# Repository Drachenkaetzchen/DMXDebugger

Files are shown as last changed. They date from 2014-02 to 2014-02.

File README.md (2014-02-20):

# DMX/RDM Adapter / RS485 Hub

This is a board which allows you to:
- Interconnect any standard DMX plugs, which includes XLR 3 pin male+female, XLR 5 pin male+female and RJ45
- Flip the data lines for each port in case of wiring error
- Connect each plug to an internal RS485 hub (in "direct" mode, each Data+/Data- lines are connected to each other)
- Terminate each port and enable/disable RX (only if port is connected to the RS485 hub)
- Connect a logic probe to the RS485 hub or to the secondary data ports (useful for the OLA logic sniffer)
- Display RX/TX status (RS485 hub mode only)
- Powered via battery (9V) or USB

# Applications

## Interconnect DMX plug formats directly

1. This mode works unpowered. You don't need to connect a battery or USB
2. Flip all switches from "TO HUB" to "DIRECT"
3. Connect exactly 2 plugs you wish to connect. If you connect more, data collisions can occur on the bus

## Interconnect DMX plug formats via the RS485 hub

1. This mode requires power. Connect a 9V battery or USB and flip the power switch to the specific "ON" position (either USB or BATTERY)
2. Flip the switches for all used ports from "DIRECT" to "HUB"
3. Connect as many plugs as you like
4. The LEDs should indicate RX/TX status

## Retrieve the data on the DMX bus via a logic analyzer

1. Set up as described in "Interconnect DMX plug formats via the RS485 hub"
2. Connect your logic probe to the GND and DATA pins on the bottom right

## Retrieve the data of the DMX secondary data lines

1. This mode works unpowered. However, you need an RS485 driver (like the SN75176) to convert the differential signal into logic levels
2. Connect your probe to the secondary data port

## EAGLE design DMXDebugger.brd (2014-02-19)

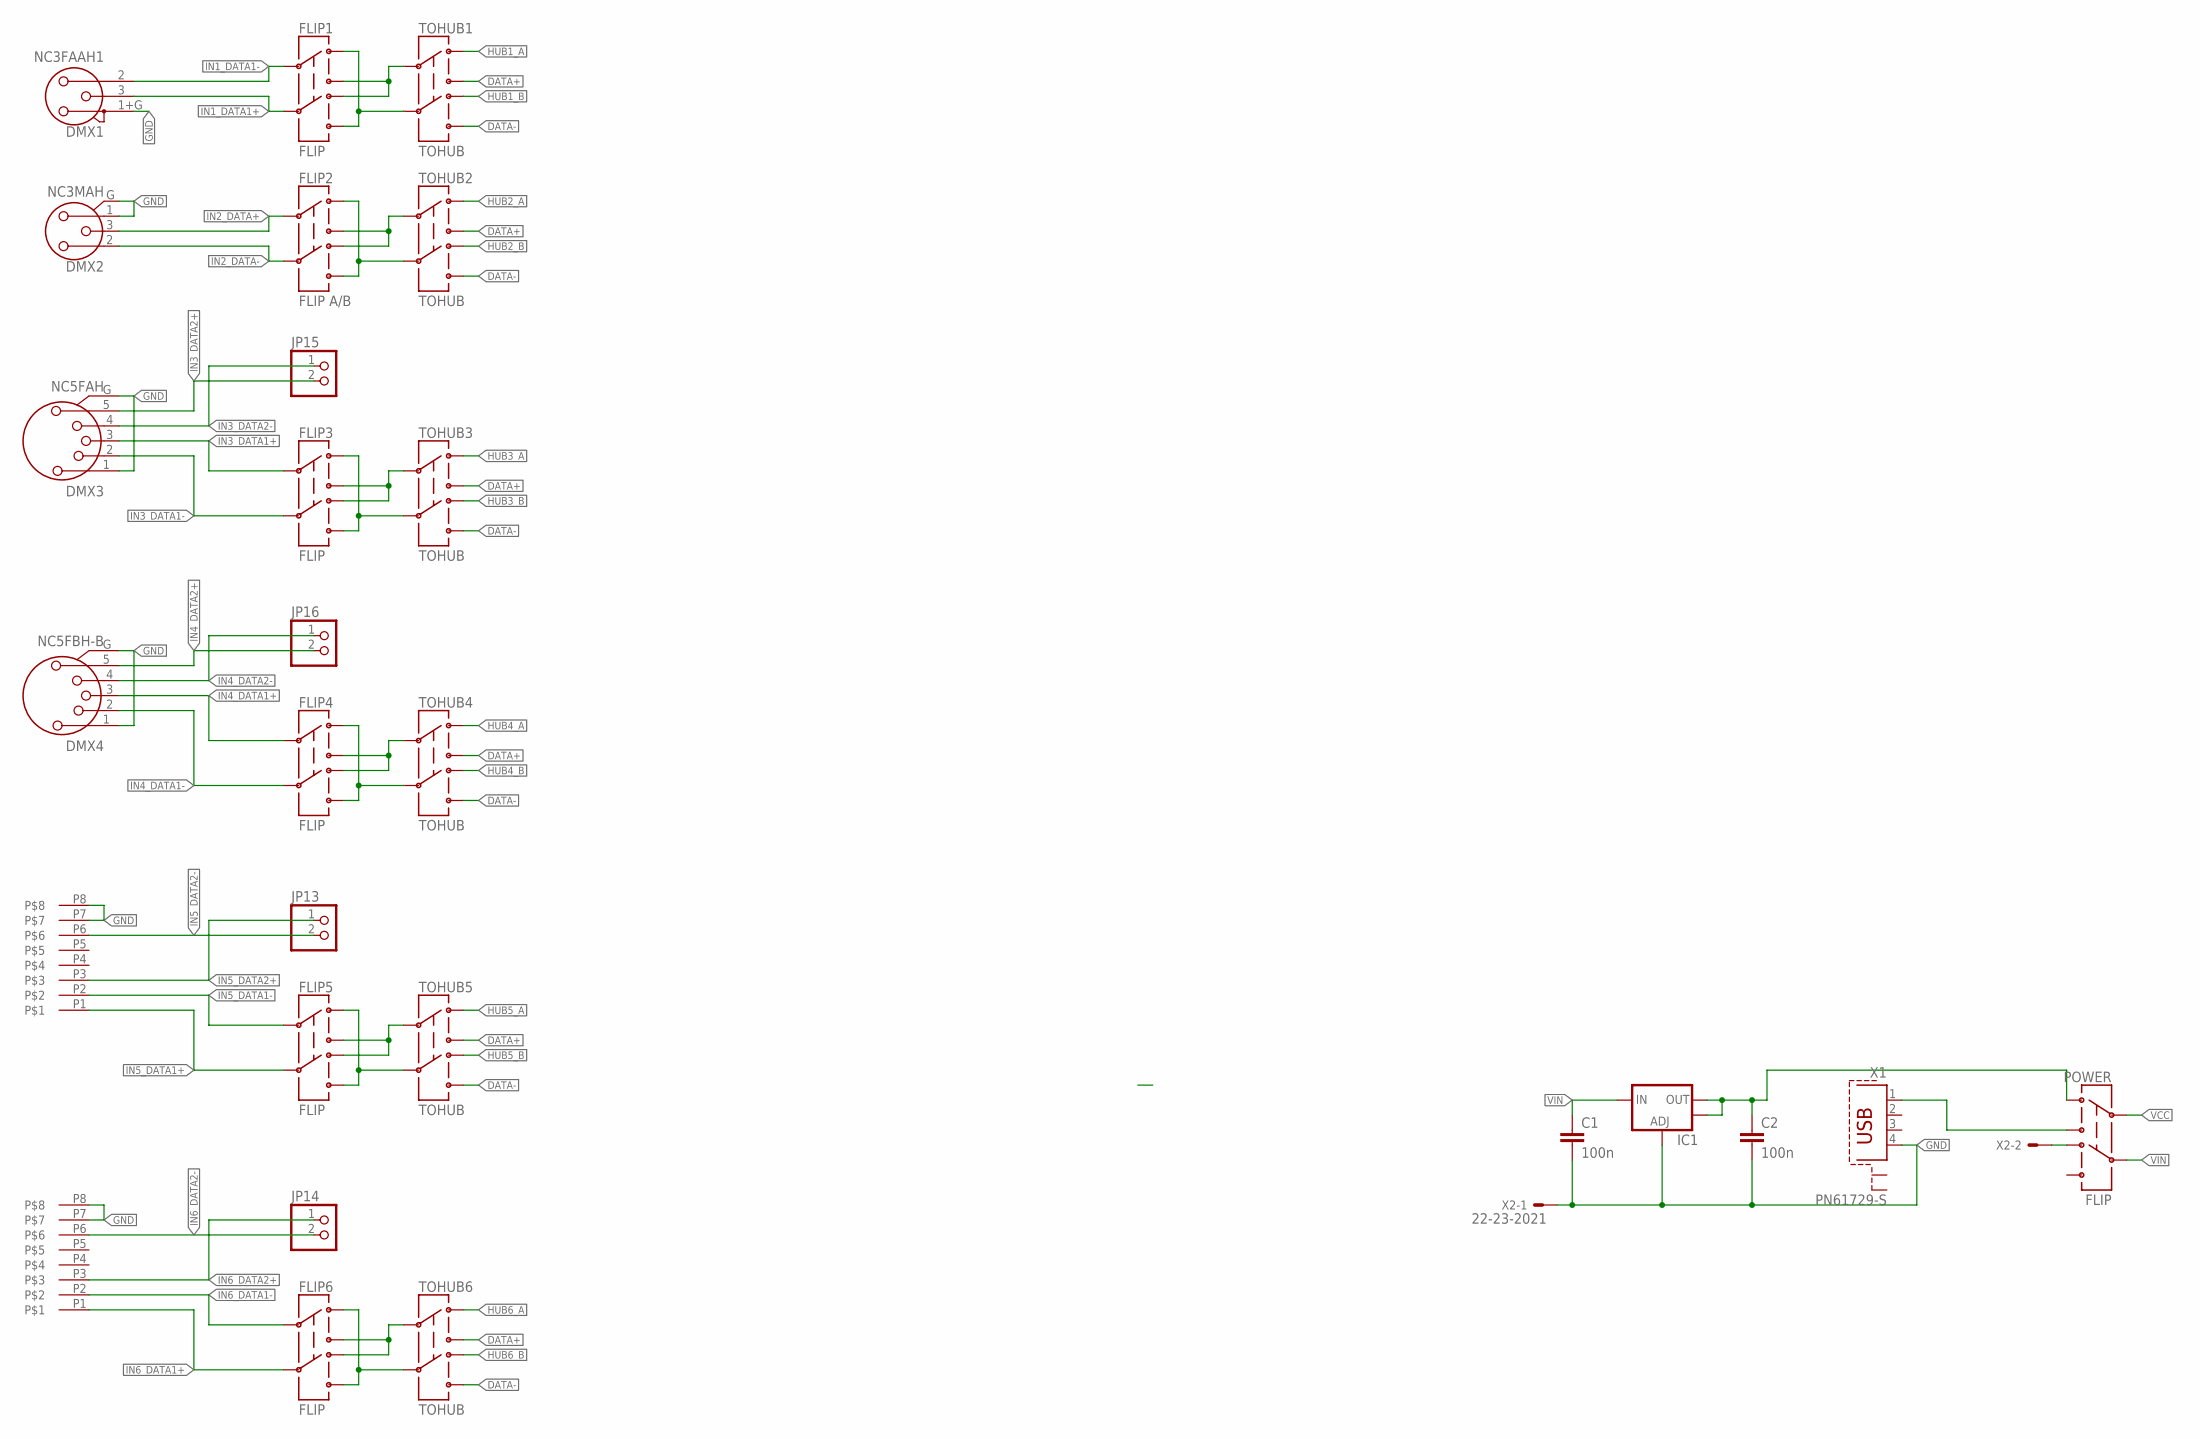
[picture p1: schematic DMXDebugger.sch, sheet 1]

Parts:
C1, C2: 100n; C1206
DMX1: NC3FAAH1; NC3FAH1
DMX2: NC3MAH; NC3FAH2
DMX3: NC5FAH
DMX4: NC5FBH-B
DMX5, DMX6: RJHS508; P-RJHS-538X
FLIP1, FLIP3, FLIP4, FLIP5, FLIP6: FLIP; MSS-2235
FLIP2: FLIP A/B; MSS-2235
IC1: V_REG_LM1117SOT223; SOT223
JP13, JP14, JP15, JP16: PINHD-1X2; 1X02
POWER: FLIP; MSS-2235
TOHUB1, TOHUB2, TOHUB3, TOHUB4, TOHUB5, TOHUB6: TOHUB; MSS-2235
X1: PN61729-S
X2: 22-23-2021

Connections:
DATA+: TOHUB1.3, TOHUB2.3, TOHUB3.3, TOHUB4.3, TOHUB5.3, TOHUB6.3
DATA-: TOHUB1.4 (6), TOHUB2.4 (6), TOHUB3.4 (6), TOHUB4.4 (6), TOHUB5.4 (6), TOHUB6.4 (6)
GND: C1.2, C2.2, DMX1.1+G (1), DMX2.1 (2), DMX2.G, DMX3.1, DMX3.G, DMX4.1, DMX4.G, DMX5.P7, DMX5.P8, DMX6.P7, DMX6.P8, IC1.1 (ADJ), X1.4, X2.1; also elsewhere on the board
HUB1_A: TOHUB1.1; also elsewhere on the board
HUB1_B: TOHUB1.6 (4); also elsewhere on the board
HUB2_A: TOHUB2.1; also elsewhere on the board
HUB2_B: TOHUB2.6 (4); also elsewhere on the board
HUB3_A: TOHUB3.1; also elsewhere on the board
HUB3_B: TOHUB3.6 (4); also elsewhere on the board
HUB4_A: TOHUB4.1; also elsewhere on the board
HUB4_B: TOHUB4.6 (4); also elsewhere on the board
HUB5_A: TOHUB5.1; also elsewhere on the board
HUB5_B: TOHUB5.6 (4); also elsewhere on the board
HUB6_A: TOHUB6.1; also elsewhere on the board
HUB6_B: TOHUB6.6 (4); also elsewhere on the board
IN1_DATA1+: DMX1.3, FLIP1.5
IN1_DATA1-: DMX1.2, FLIP1.2
IN2_DATA+: DMX2.3, FLIP2.2
IN2_DATA-: DMX2.2 (1), FLIP2.5
IN3_DATA1+: DMX3.3, FLIP3.2
IN3_DATA1-: DMX3.2, FLIP3.5
IN3_DATA2+: DMX3.5, JP15.2
IN3_DATA2-: DMX3.4, JP15.1
IN4_DATA1+: DMX4.3, FLIP4.2
IN4_DATA1-: DMX4.2, FLIP4.5
IN4_DATA2+: DMX4.5, JP16.2
IN4_DATA2-: DMX4.4, JP16.1
IN5_DATA1+: DMX5.P1, FLIP5.5
IN5_DATA1-: DMX5.P2, FLIP5.2
IN5_DATA2+: DMX5.P3, JP13.1
IN5_DATA2-: DMX5.P6, JP13.2
IN6_DATA1+: DMX6.P1, FLIP6.5
IN6_DATA1-: DMX6.P2, FLIP6.2
IN6_DATA2+: DMX6.P3, JP14.1
IN6_DATA2-: DMX6.P6, JP14.2
unnamed: POWER.6 (4), X2.2
unnamed: POWER.3, X1.1
unnamed: FLIP1.3, FLIP1.6 (4), TOHUB1.2
unnamed: FLIP1.1, FLIP1.4 (6), TOHUB1.5
unnamed: FLIP2.1, FLIP2.4 (6), TOHUB2.5
unnamed: FLIP2.3, FLIP2.6 (4), TOHUB2.2
unnamed: FLIP3.1, FLIP3.4 (6), TOHUB3.5
unnamed: FLIP4.1, FLIP4.4 (6), TOHUB4.5
unnamed: FLIP5.1, FLIP5.4 (6), TOHUB5.5
unnamed: FLIP3.3, FLIP3.6 (4), TOHUB3.2
unnamed: FLIP4.3, FLIP4.6 (4), TOHUB4.2
unnamed: FLIP5.3, FLIP5.6 (4), TOHUB5.2
unnamed: FLIP6.1, FLIP6.4 (6), TOHUB6.5
unnamed: FLIP6.3, FLIP6.6 (4), TOHUB6.2
VCC: POWER.2; also elsewhere on the board
VIN: C1.1, IC1.3 (IN), POWER.5
VOUT: C2.1, IC1.2 (OUT), IC1.4 (OUT), POWER.1

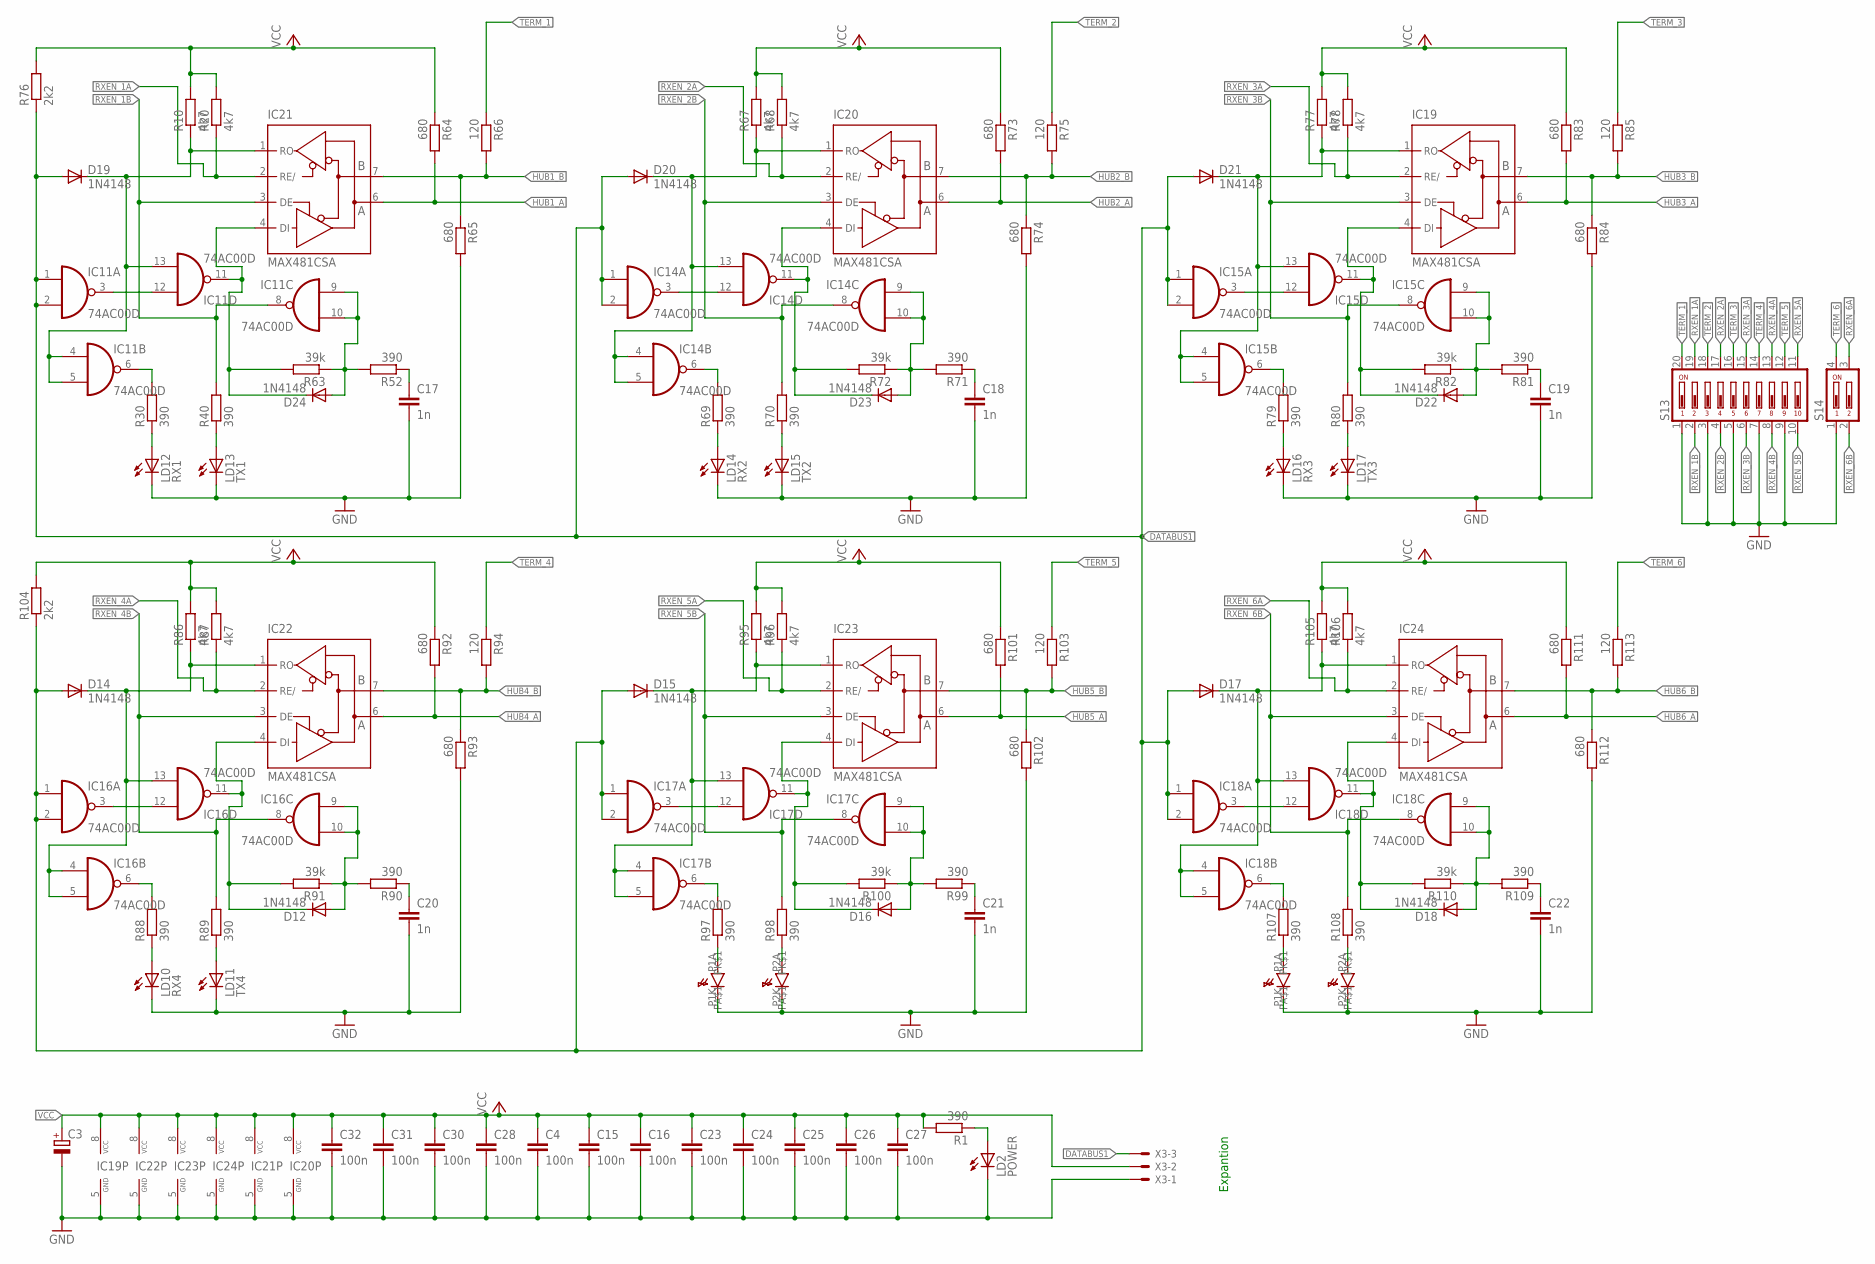
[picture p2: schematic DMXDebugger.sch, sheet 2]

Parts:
C3: CPOL-EUD; PANASONIC_D
C4, C15, C16, C23, C24, C25, C26, C27, C28, C30, C31, C32: 100n; C1206
C17, C18, C19, C20, C21, C22: 1n; C1206
D12, D14, D15, D16, D17, D18, D19, D20, D21, D22, D23, D24: 1N4148; MINIMELF
DMX5, DMX6: RJHS508; P-RJHS-538X
IC11, IC14, IC15, IC16, IC17, IC18: 74AC00D; SO14
IC19, IC20, IC21, IC22, IC23, IC24: MAX481CSA; SO08
LD2: POWER; CHIP-LED0603
LD10: RX4; CHIP-LED0603
LD11: TX4; CHIP-LED0603
LD12: RX1; CHIP-LED0603
LD13: TX1; CHIP-LED0603
LD14: RX2; CHIP-LED0603
LD15: TX2; CHIP-LED0603
LD16: RX3; CHIP-LED0603
LD17: TX3; CHIP-LED0603
R1, R30, R40, R52, R69, R70, R71, R79, R80, R81, R88, R89, R90, R97, R98, R99, R107, R108, R109: 390; R1206
R10, R20, R67, R68, R77, R78, R86, R87, R95, R96, R105, R106: 4k7; R1206
R63, R72, R82, R91, R100, R110: 39k; R1206
R64, R65, R73, R74, R83, R84, R92, R93, R101, R102, R111, R112: 680; R1206
R66, R75, R85, R94, R103, R113: 120; R1206
R76, R104: 2k2; R1206
S13: DIP10YL
S14: DIP02YL
X3: 22-23-2031

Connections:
DATABUS1: D14.A, D15.A, D17.A, D19.A, D20.A, D21.A, IC11.1 (I0), IC11.2 (I1), IC14.1 (I0), IC14.2 (I1), IC15.1 (I0), IC15.2 (I1), IC16.1 (I0), IC16.2 (I1), IC17.1 (I0), IC17.2 (I1), IC18.1 (I0), IC18.2 (I1), R76.1, R104.1, X3.3
GND: C3.-, C4.2, C15.2, C16.2, C17.2, C18.2, C19.2, C20.2, C21.2, C22.2, C23.2, C24.2, C25.2, C26.2, C27.2, C28.2, C30.2, C31.2, C32.2, DMX5.P1K (PK$1), DMX5.P2K (PK$1), DMX6.P1K (PK$1), DMX6.P2K (PK$1), IC11.7 (GND), IC14.7 (GND), IC15.7 (GND), IC16.7 (GND), IC17.7 (GND), IC18.7 (GND), IC19.5 (GND), IC20.5 (GND), IC21.5 (GND), IC22.5 (GND), IC23.5 (GND), IC24.5 (GND), LD2.C, LD10.C, LD11.C, LD12.C, LD13.C, LD14.C, LD15.C, LD16.C, LD17.C, R65.2, R74.2, R84.2, R93.2, R102.2, R112.2, S13.1, S13.3, S13.5, S13.7, S13.9, S14.1, X3.1; also elsewhere on the board
HUB1_A: IC21.6 (A), R64.2; also elsewhere on the board
HUB1_B: IC21.7 (B), R65.1, R66.2; also elsewhere on the board
HUB2_A: IC20.6 (A), R73.2; also elsewhere on the board
HUB2_B: IC20.7 (B), R74.1, R75.2; also elsewhere on the board
HUB3_A: IC19.6 (A), R83.2; also elsewhere on the board
HUB3_B: IC19.7 (B), R84.1, R85.2; also elsewhere on the board
HUB4_A: IC22.6 (A), R92.2; also elsewhere on the board
HUB4_B: IC22.7 (B), R93.1, R94.2; also elsewhere on the board
HUB5_A: IC23.6 (A), R101.2; also elsewhere on the board
HUB5_B: IC23.7 (B), R102.1, R103.2; also elsewhere on the board
HUB6_A: IC24.6 (A), R111.2; also elsewhere on the board
HUB6_B: IC24.7 (B), R112.1, R113.2; also elsewhere on the board
unnamed: LD2.A, R1.1
unnamed: LD13.A, R40.1
unnamed: LD12.A, R30.1
unnamed: D19.C, IC11.4 (I0), IC11.5 (I1), IC11.13 (I1), IC21.1 (RO), R10.1
unnamed: IC11.3 (O), IC11.12 (I0)
unnamed: IC11.6 (O), R30.2
unnamed: D24.A, IC11.9 (I0), IC11.10 (I1), R52.2, R63.1
unnamed: D24.C, IC11.11 (O), IC21.4 (DI), R63.2
unnamed: C17.1, R52.1
unnamed: LD15.A, R70.1
unnamed: LD14.A, R69.1
unnamed: D20.C, IC14.4 (I0), IC14.5 (I1), IC14.13 (I1), IC20.1 (RO), R67.1
unnamed: IC14.3 (O), IC14.12 (I0)
unnamed: IC14.6 (O), R69.2
unnamed: D23.A, IC14.9 (I0), IC14.10 (I1), R71.2, R72.1
unnamed: D23.C, IC14.11 (O), IC20.4 (DI), R72.2
unnamed: C18.1, R71.1
unnamed: LD17.A, R80.1
unnamed: LD16.A, R79.1
unnamed: D21.C, IC15.4 (I0), IC15.5 (I1), IC15.13 (I1), IC19.1 (RO), R77.1
unnamed: IC15.3 (O), IC15.12 (I0)
unnamed: IC15.6 (O), R79.2
unnamed: D22.A, IC15.9 (I0), IC15.10 (I1), R81.2, R82.1
unnamed: D22.C, IC15.11 (O), IC19.4 (DI), R82.2
unnamed: C19.1, R81.1
unnamed: LD11.A, R89.1
unnamed: LD10.A, R88.1
unnamed: D14.C, IC16.4 (I0), IC16.5 (I1), IC16.13 (I1), IC22.1 (RO), R86.1
unnamed: IC16.3 (O), IC16.12 (I0)
unnamed: IC16.6 (O), R88.2
unnamed: D12.A, IC16.9 (I0), IC16.10 (I1), R90.2, R91.1
unnamed: D12.C, IC16.11 (O), IC22.4 (DI), R91.2
unnamed: C20.1, R90.1
unnamed: DMX5.P2A (PA$1), R98.1
unnamed: DMX5.P1A (PA$1), R97.1
unnamed: D15.C, IC17.4 (I0), IC17.5 (I1), IC17.13 (I1), IC23.1 (RO), R95.1
unnamed: IC17.3 (O), IC17.12 (I0)
unnamed: IC17.6 (O), R97.2
unnamed: D16.A, IC17.9 (I0), IC17.10 (I1), R99.2, R100.1
unnamed: D16.C, IC17.11 (O), IC23.4 (DI), R100.2
unnamed: C21.1, R99.1
unnamed: DMX6.P2A (PA$1), R108.1
unnamed: DMX6.P1A (PA$1), R107.1
unnamed: D17.C, IC18.4 (I0), IC18.5 (I1), IC18.13 (I1), IC24.1 (RO), R105.1
unnamed: IC18.3 (O), IC18.12 (I0)
unnamed: IC18.6 (O), R107.2
unnamed: D18.A, IC18.9 (I0), IC18.10 (I1), R109.2, R110.1
unnamed: D18.C, IC18.11 (O), IC24.4 (DI), R110.2
unnamed: C22.1, R109.1
RXEN_1A: IC21.2 (RE/), R20.1, S13.19
RXEN_1B: IC11.8 (O), IC21.3 (DE), R40.2, S13.2
RXEN_2A: IC20.2 (RE/), R68.1, S13.17
RXEN_2B: IC14.8 (O), IC20.3 (DE), R70.2, S13.4
RXEN_3A: IC19.2 (RE/), R78.1, S13.15
RXEN_3B: IC15.8 (O), IC19.3 (DE), R80.2, S13.6
RXEN_4A: IC22.2 (RE/), R87.1, S13.13
RXEN_4B: IC16.8 (O), IC22.3 (DE), R89.2, S13.8
RXEN_5A: IC23.2 (RE/), R96.1, S13.11
RXEN_5B: IC17.8 (O), IC23.3 (DE), R98.2, S13.10
RXEN_6A: IC24.2 (RE/), R106.1, S14.3
RXEN_6B: IC18.8 (O), IC24.3 (DE), R108.2, S14.2
TERM_1: R66.1, S13.20
TERM_2: R75.1, S13.18
TERM_3: R85.1, S13.16
TERM_4: R94.1, S13.14
TERM_5: R103.1, S13.12
TERM_6: R113.1, S14.4
VCC: C3.+, C4.1, C15.1, C16.1, C23.1, C24.1, C25.1, C26.1, C27.1, C28.1, C30.1, C31.1, C32.1, IC11.14 (VCC), IC14.14 (VCC), IC15.14 (VCC), IC16.14 (VCC), IC17.14 (VCC), IC18.14 (VCC), IC19.8 (VCC), IC20.8 (VCC), IC21.8 (VCC), IC22.8 (VCC), IC23.8 (VCC), IC24.8 (VCC), R1.2, R10.2, R20.2, R64.1, R67.2, R68.2, R73.1, R76.2, R77.2, R78.2, R83.1, R86.2, R87.2, R92.1, R95.2, R96.2, R101.1, R104.2, R105.2, R106.2, R111.1, X3.2; also elsewhere on the board

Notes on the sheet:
Expantion

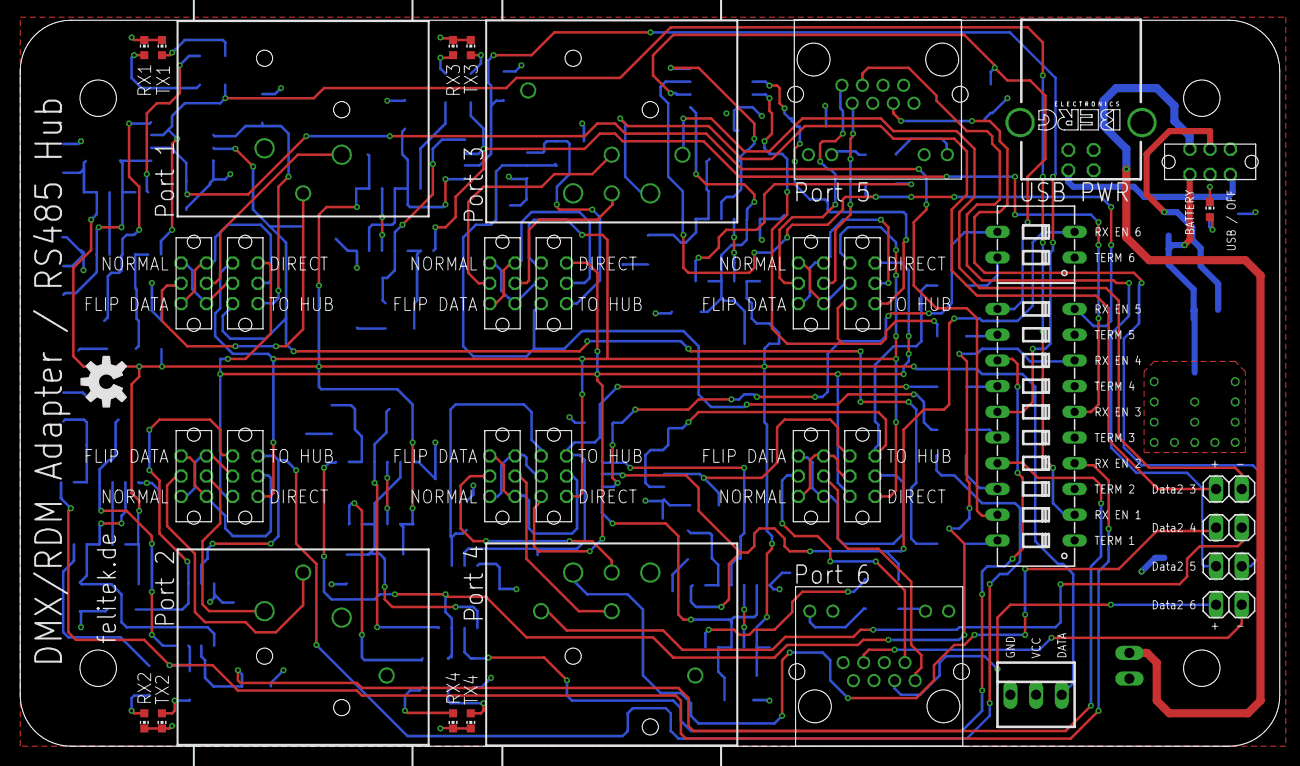
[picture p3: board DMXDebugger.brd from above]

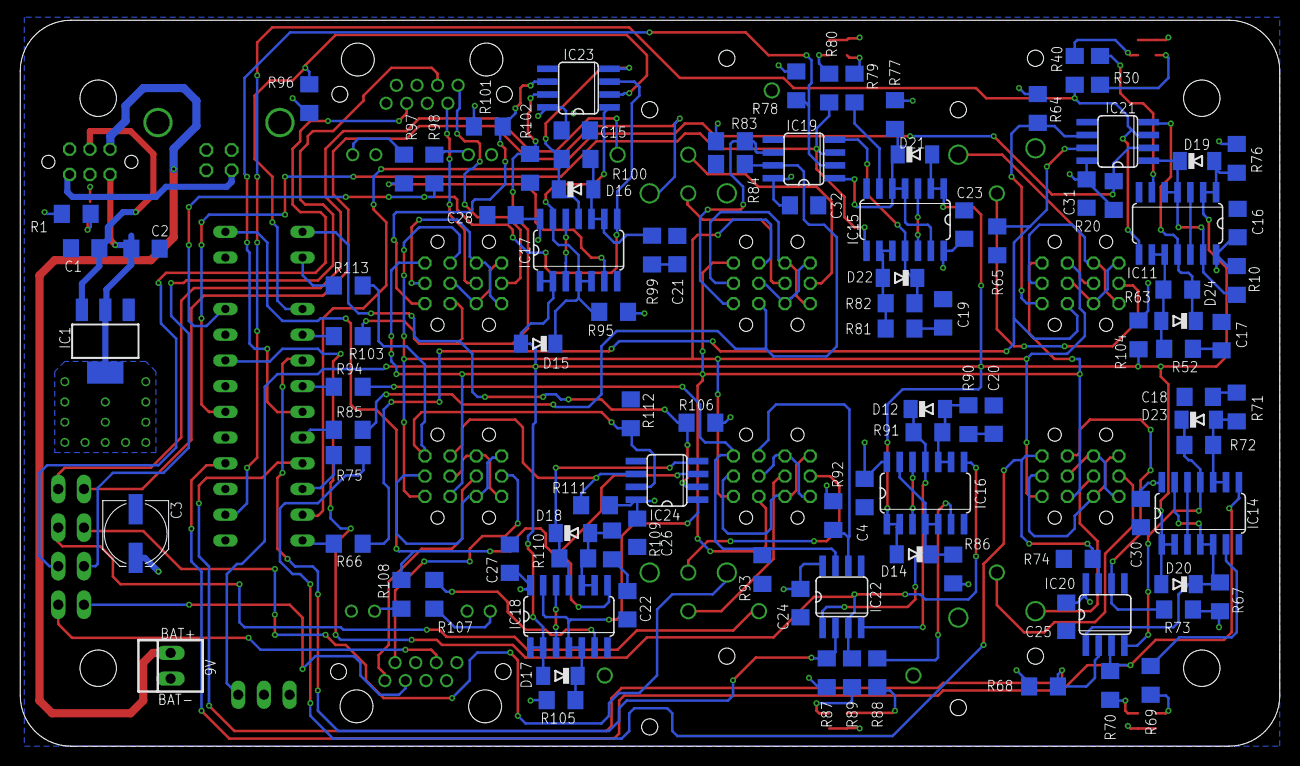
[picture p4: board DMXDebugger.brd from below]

Board: 2 copper layers, 124.4 x 71.7 mm, 141 parts (104 on the bottom side), 120 nets.

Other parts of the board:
U$1: OSHW-LOGO-M

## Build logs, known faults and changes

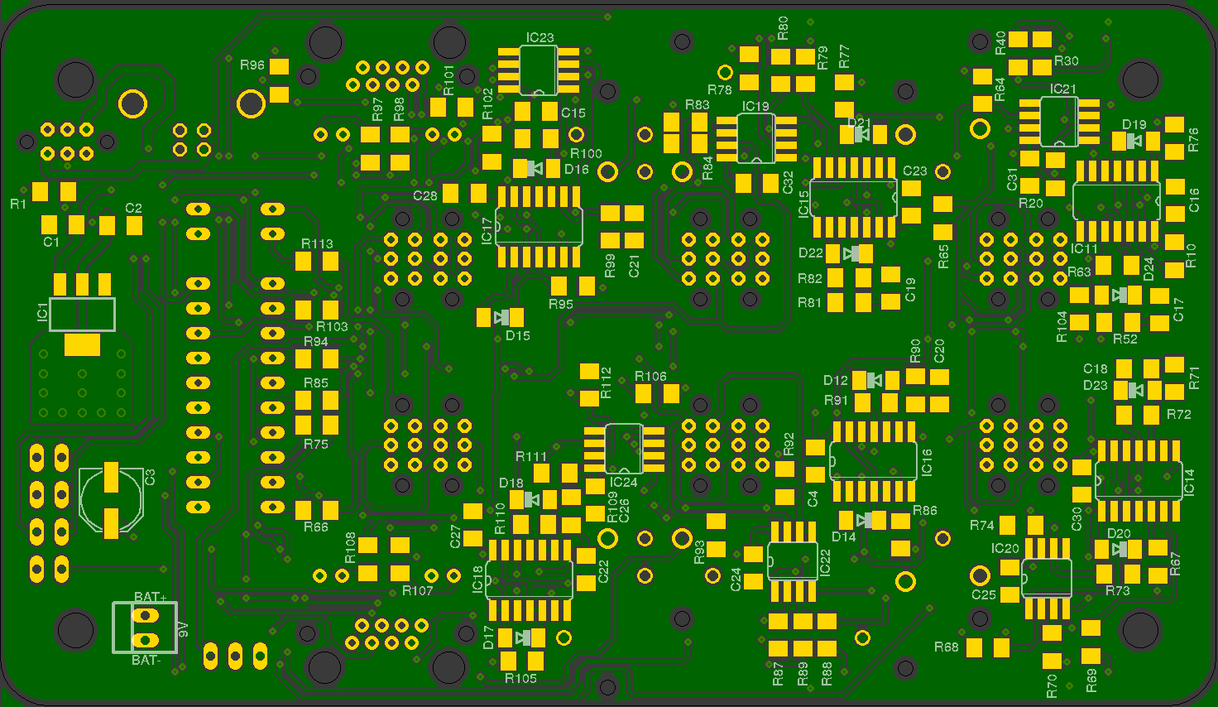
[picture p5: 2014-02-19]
DMXDebugger_bot.png

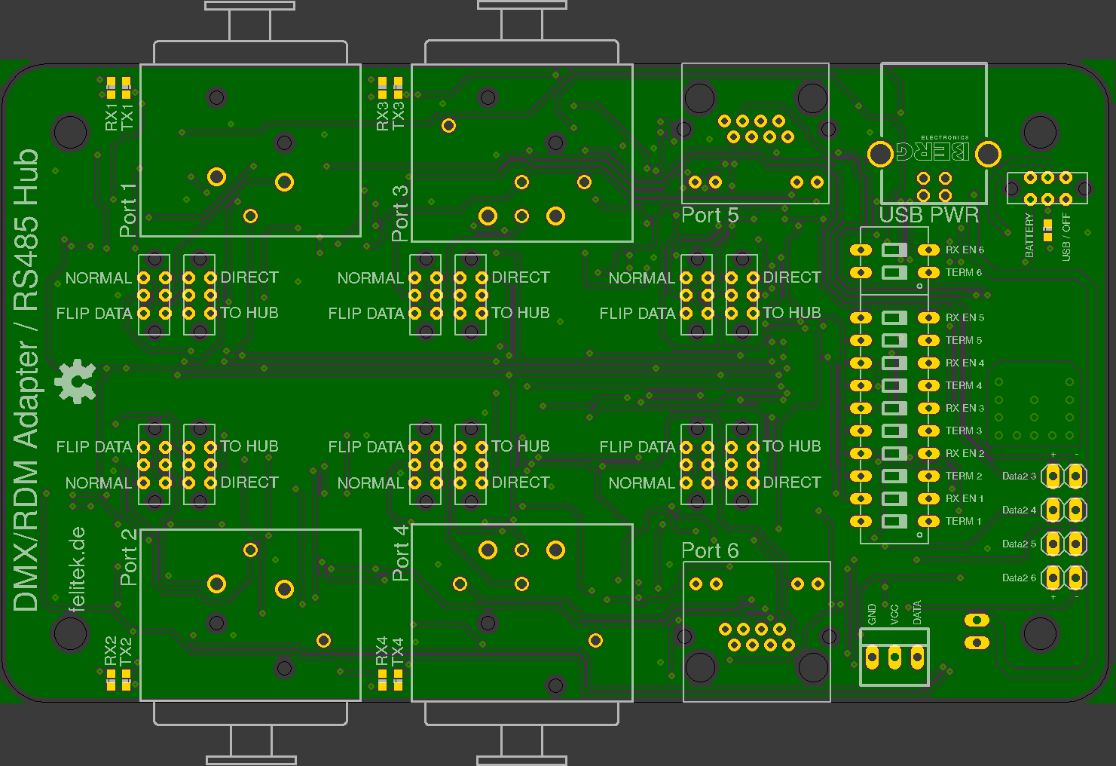
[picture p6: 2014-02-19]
DMXDebugger_top.png

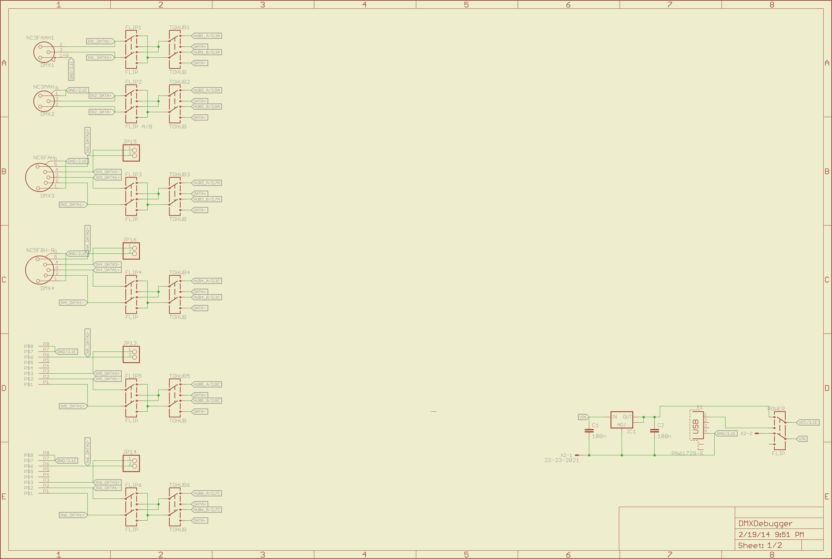
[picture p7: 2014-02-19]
DMXDebugger_sheet1.png

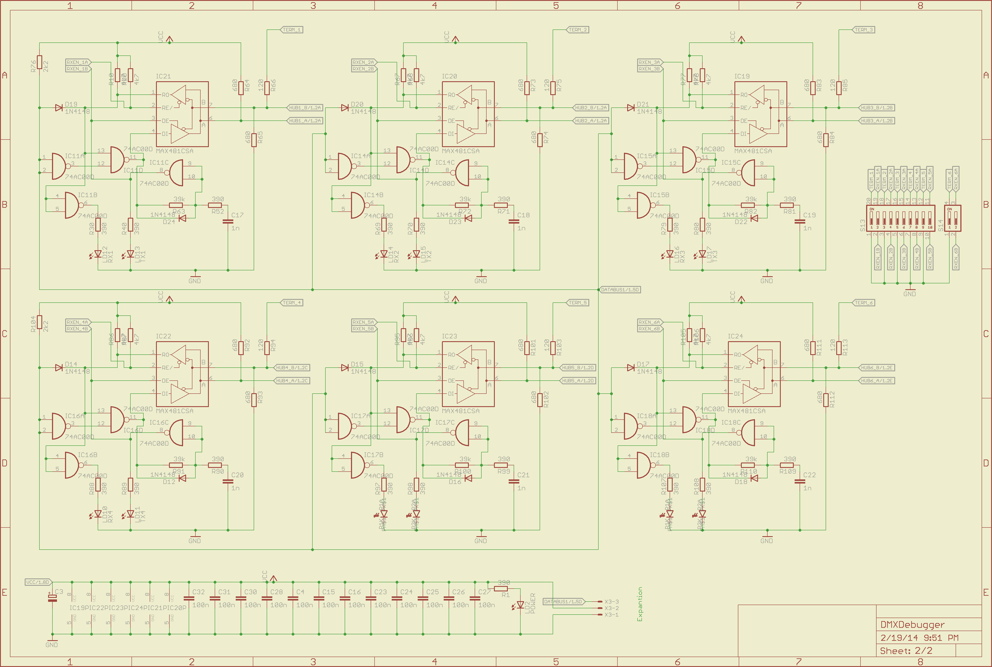
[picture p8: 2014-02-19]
DMXDebugger_sheet2.png

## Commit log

2014-02-19 Moved LEDs from tValues to tNames
    [DMXDebugger.brd]
2014-02-19 Fixed forgotten unrouted trace (it was below a pad, so it wouldn't matter) Moved the felitek.de URL in line with the OSHW logo
    [DMXDebugger.brd]

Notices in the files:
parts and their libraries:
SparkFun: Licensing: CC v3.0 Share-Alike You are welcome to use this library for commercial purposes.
